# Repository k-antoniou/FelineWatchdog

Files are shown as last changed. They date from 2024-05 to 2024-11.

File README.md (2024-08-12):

# 🐱 Feline Watchdog: Missing Cat Alert System
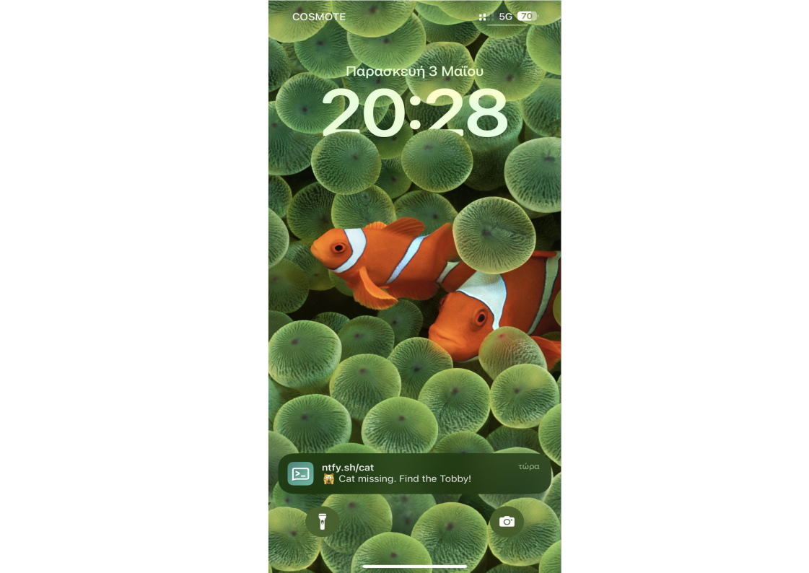
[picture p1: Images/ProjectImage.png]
ProjectImage


Feline Watchdog is an ESP32-based system designed to monitor the Wi-Fi connection between your cat's collar-mounted ESP32 device and your home network. If the Wi-Fi connection is lost, indicating that your cat may have wandered out of range, the system sends a notification to your iOS or Android device using the ntfy Linux tool.

## Overview

Have you ever worried about your cat wandering too far from home? Feline Watchdog provides peace of mind by alerting you when your cat goes missing. By monitoring the Wi-Fi connection between your cat's collar-mounted ESP32 device and your home network, Feline Watchdog can detect when your cat is out of range and send you an alert notification on your mobile device.

## 🔧 Prerequisites

- ESP32 microcontroller
- Raspberry Pi (Optional)
- Docker (if using Raspberry Pi)
- Router (if not using Raspberry Pi)

## Embedded System Configuration

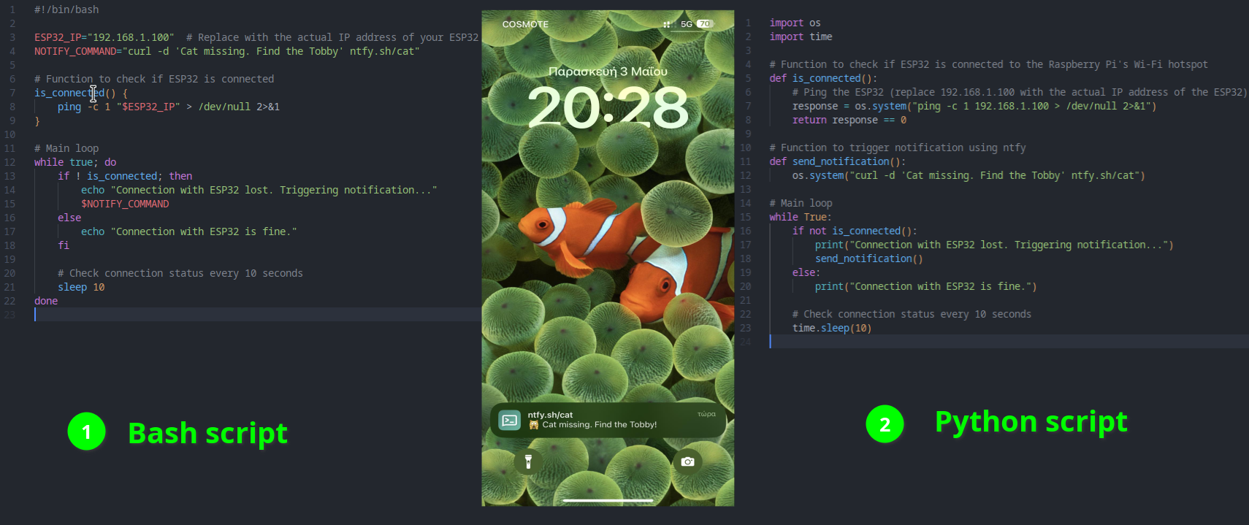
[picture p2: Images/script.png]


<p align="center">
  <b>Two implementations of Embedded System Configuration</b>
</p>

### Option 1: With Raspberry Pi

1. **Setting Up a Wi-Fi Hotspot on Embedded System**

   - For detailed instructions on setting up a Wi-Fi hotspot on your embedded system, please refer to the [Wi-Fi Hotspot Setup Instructions](WiFi_hotspot.md).

   - Use the provided bash script using the **nmcli** tool to create a Wi-Fi hotspot on the Raspberry Pi. 
    ```bash
    bash create_hotspot.sh
    ```
    or
    ```bash
    ./create_hotspot.sh
    ```
  2. **Install Docker on your Raspberry Pi**
  ```bash
  sudo docker --version
  Docker version 20.10.21, build 20.10.21-0ubuntu1~18.04.3
  ```
  ```bash
  docker run \
    -v /var/cache/ntfy:/var/cache/ntfy \
    -v /etc/ntfy:/etc/ntfy \
    -p 80:80 \
    -itd \
    binwiederhier/ntfy \
      serve \
      --cache-file /var/cache/ntfy/cache.db
  ```
## 📡 ESP32 Configuration and Notification Setup

### Option 1: Using Raspberry Pi as a Wi-Fi Hotspot

1. **ESP32 Configuration**
   - Upload the `cat.ino` code to your ESP32.
   - The ESP32 will connect to the Wi-Fi hotspot created by the Raspberry Pi.
   - Once connected, the assigned IP address will be printed to the serial monitor.

2. **Raspberry Pi Monitoring and Notification**
   - The Raspberry Pi continuously monitors the connection status of the ESP32.
   - If the connection is lost, it triggers a notification using ntfy.

### Option 2: Direct Connection to Router

For a basic example of using NTFY with ESP boards, check out the [ntfy_on_a_chip repository](https://github.com/gergepalfi/ntfy_on_a_chip). It provides a foundational setup for communicating with the NTFY server and can be adapted for various projects, including this.

1. **Connect ESP32 Directly to Router**
   - Configure your ESP32 to connect directly to your home Wi-Fi network (router).

2. **ESP32 Configuration**
   - Upload the `cat.ino` code to your ESP32.
   - The ESP32 will connect to the specified Wi-Fi network and print the assigned IP address to the serial monitor.

3. **Notification Setup**
   - Set up ntfy or another notification service on a server or computer within your home network.
   - This service will monitor the connection status of the ESP32.
   - If the connection is lost, it triggers a notification using ntfy or a similar service.

### Notes
- Ensure that your network's firewall settings allow communication between the ESP32 and the notification service.
- Configure ntfy or your chosen notification service according to the service's documentation for optimal performance.

## 🔩 PCB Design

  ### Dual Power Sources: Li-ion Battery and USB

  This setup allows the ESP32 to be powered either by a Li-ion battery or directly from a USB source via a voltage regulator.

  ### Li-ion Battery Connection
  - The Li-ion battery is connected to the **BATT+** and **BATT-** terminals of the charger module.
  - **BATT+** from the charger module is connected to the 3.3V input of the ESP32 through a Schottky diode.
  - **BATT-** is connected to the GND of the ESP32.

  ### USB Power Connection (For Re-programming)
  - The 5V line from the USB is connected to the **VIN** of the voltage regulator.
  - **GND** from the USB is connected to the GND of the voltage regulator.
  - The 3.3V output of the voltage regulator is connected to the 3.3V input of the ESP32 through a Schottky diode.

  Screenshots from KiCad:

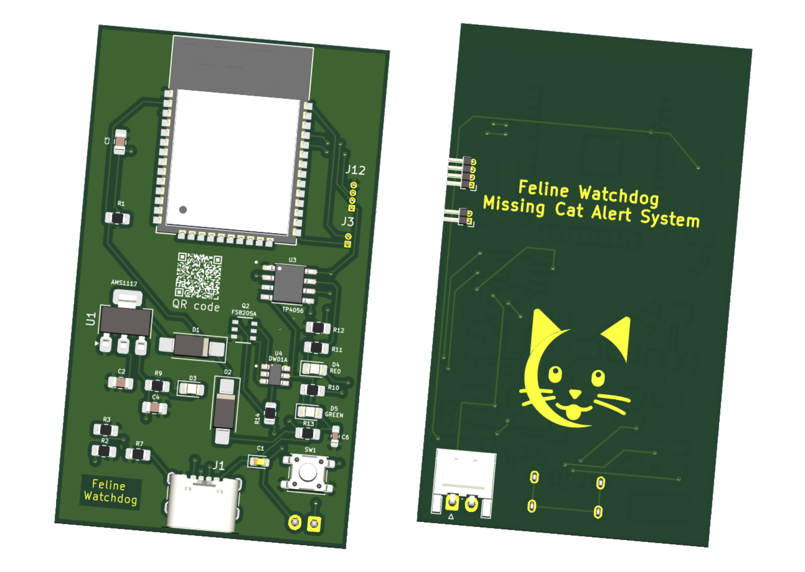
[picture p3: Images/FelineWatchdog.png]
  

  Screenshots from Fusion 360:

  ### Important Notes
  - Schottky diodes are used to prevent backfeeding between the battery and USB power sources.

  ## 🏗️ 3D Design

  Screenshots from Fusion 360:
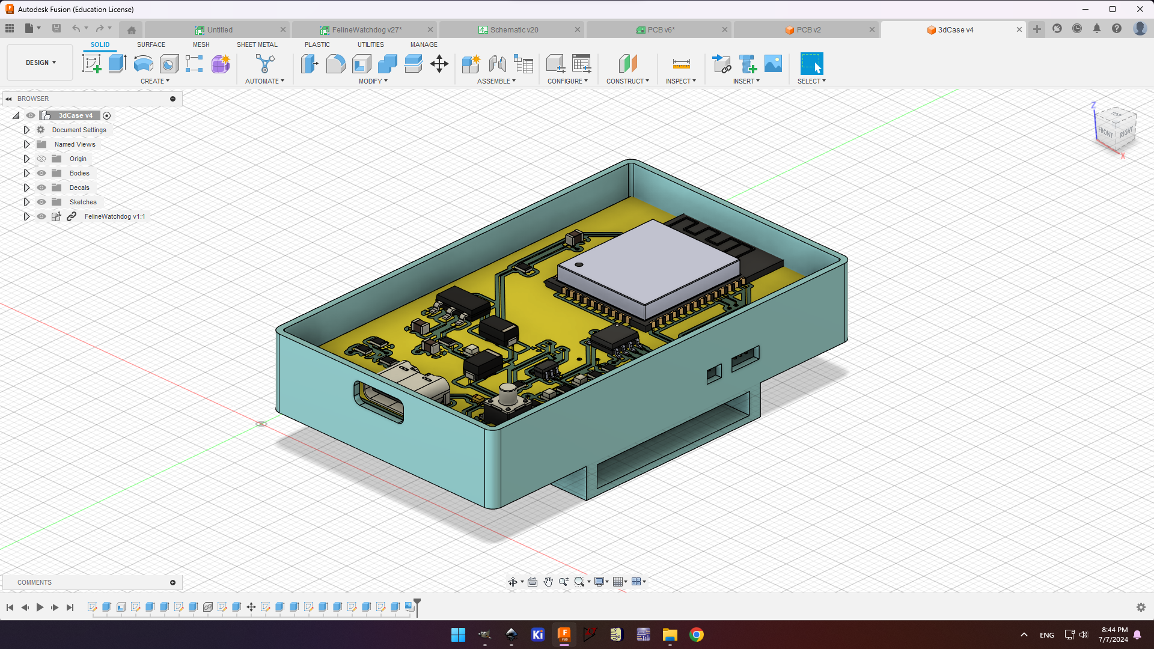
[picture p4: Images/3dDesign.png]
  

  ## 3D Printed Case

  Screenshots of the printed 3D case:
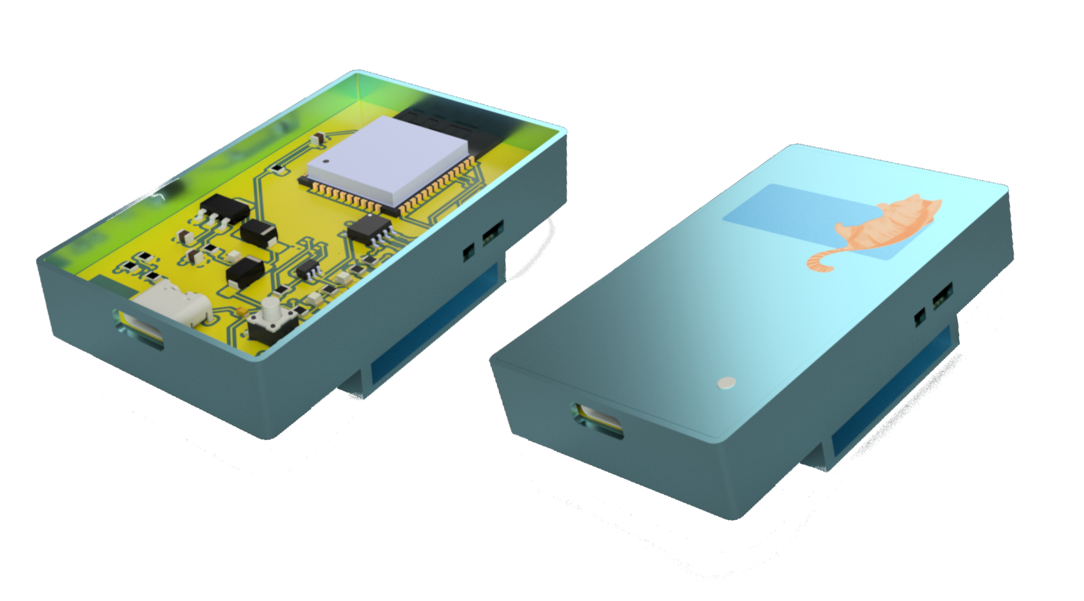
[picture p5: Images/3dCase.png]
  

  ## To Do

  - [x] Implement notification functionality using ntfy for sending alerts to iOS or Android devices.
  - [x] Implementation without a middle point such as Raspberry Pi, but directly with a router and ESP32.
  - [ ] Lower power consumption.
  - [ ] Implement HTTP communication method for sending alerts to a designated endpoint.
  - [ ] Implement MQTT communication method for publishing messages to a specific topic on an MQTT broker.
  - [ ] Ensure seamless integration of these functionalities within a Docker container on the Raspberry Pi.
  - [ ] Document setup and configuration steps for each notification method.
  - [ ] Test and validate the system's functionality across different scenarios.
  - [ ] Gather feedback and suggestions from users for further enhancements.

  ## 🧑‍💻 Authors

  - 

  - 

  ## 👥 Contributors

  Contributions are welcome! Feel free to submit pull requests or open issues if you encounter any problems.

   ## 🙏 Acknowledgements

   - A special thanks to the [ntfy_on_a_chip](https://github.com/gergepalfi/ntfy_on_a_chip) repository by [Gerge](https://github.com/gergepalfi). The example code and documentation provided were instrumental in implementing the direct connection option for the Feline Watchdog project. The guidance on using NTFY with ESP boards and the detailed explanation of HTTPS communication enabled us to streamline our setup by connecting the ESP32 directly to a router without needing an intermediate server like a Raspberry Pi. Your work greatly facilitated our development process and contributed to the success of the Feline Watchdog system. Thank you!

   - We would also like to acknowledge the creators of the [ntfy](https://ntfy.sh) app. The app’s simplicity and functionality made it easy to send and receive notifications, which is a core feature of the Feline Watchdog system. The ability to integrate it seamlessly into our project greatly enhanced its effectiveness.

   ## 📜 License
   
   This project is licensed under the [GPLv3 License](https://opensource.org/licenses/GPL-3.0) - see the [LICENSE](LICENSE) file for details.

   - 

**Thank you for visiting FelineWatchdog!** ✨

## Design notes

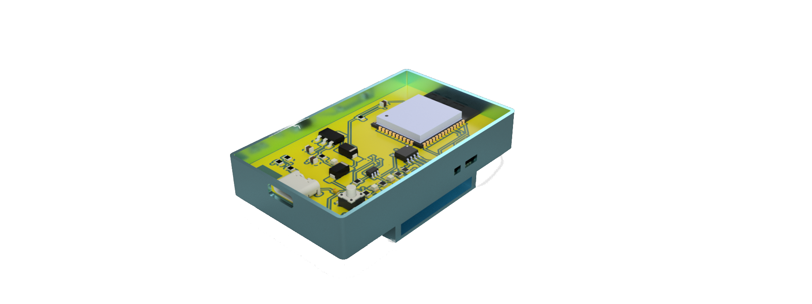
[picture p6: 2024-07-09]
Images/3dCaseOpened.png

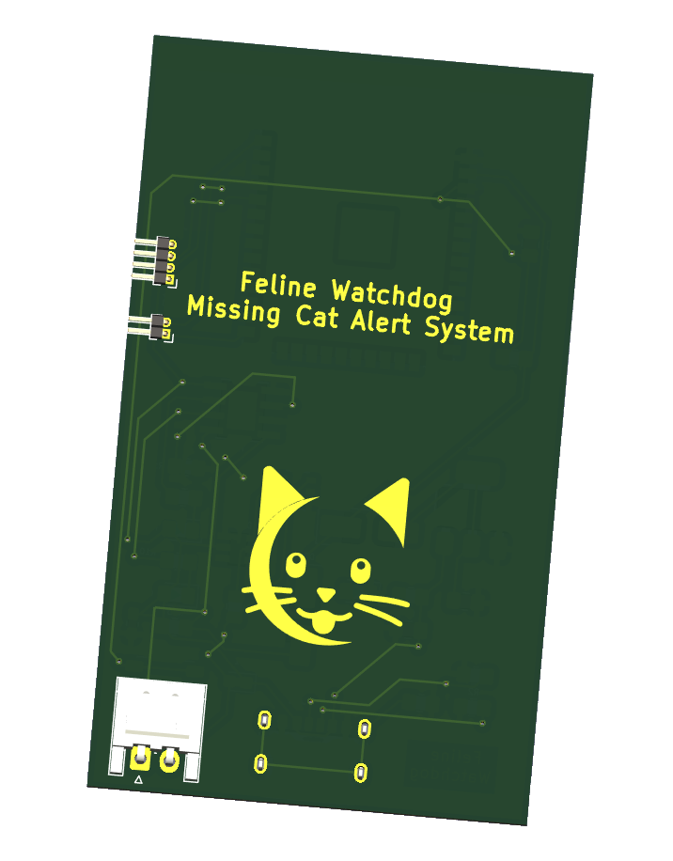
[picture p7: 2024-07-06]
Images/FelineWatchdog2.png

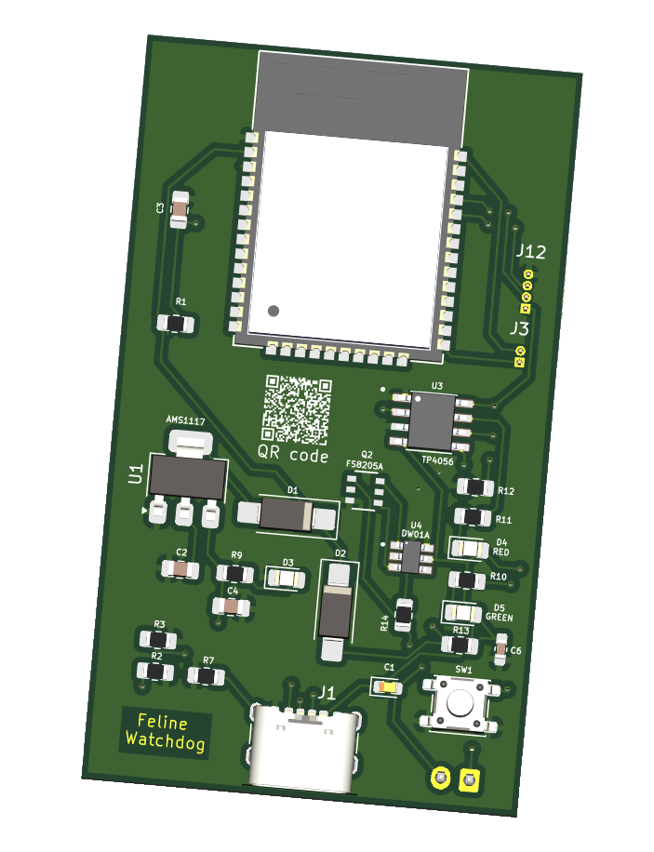
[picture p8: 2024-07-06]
Images/FelineWatchdog1.png

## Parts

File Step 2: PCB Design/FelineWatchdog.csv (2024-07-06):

Reference | Value | Datasheet | Footprint | Qty | DNP
C1 | 0.1uf | ~ | Capacitor_Tantalum_SMD:CP_EIA-1608-08_AVX-J | 1
C2,C3,C4 | 10uF | ~ | Capacitor_SMD:C_0805_2012Metric_Pad1.18x1.45mm_HandSolder | 3
C6 | 0.1uF | ~ | Capacitor_SMD:C_0603_1608Metric_Pad1.08x0.95mm_HandSolder | 1
D1,D2 | SS14 | https://www.vishay.com/docs/88746/ss12.pdf | Diode_SMD:D_SMA_Handsoldering | 2
D3 | LED | ~ | LED_SMD:LED_0805_2012Metric_Pad1.15x1.40mm_HandSolder | 1
D4 | RED | ~ | LED_SMD:LED_0805_2012Metric_Pad1.15x1.40mm_HandSolder | 1
D5 | GREEN | ~ | LED_SMD:LED_0805_2012Metric_Pad1.15x1.40mm_HandSolder | 1
J1 | USB_C_Receptacle_PowerOnly_6P | https://www.usb.org/sites/default/files/documents/usb_type-c.zip | Connector_USB:USB_C_Receptacle_GCT_USB4125-xx-x-0190_6P_TopMnt_Horizontal | 1
J2 | Conn_01x02_Socket | ~ | Connector_JST:JST_EH_S2B-EH_1x02_P2.50mm_Horizontal | 1
J3 | Conn_01x02_Pin | ~ | Connector_PinHeader_1.00mm:PinHeader_1x02_P1.00mm_Horizontal | 1
J9 | USB_B_Micro | ~ | Connector_USB:USB_Micro-B_Amphenol_10118194_Horizontal | 1
J12 | Conn_01x04_Socket | ~ | Connector_PinHeader_1.00mm:PinHeader_1x04_P1.00mm_Horizontal | 1
Q2 | FS8205A | FS8205A | ul_FS8205A:SOT-23-6L_TCP-L | 1
R1,R12 | 10k | ~ | Resistor_SMD:R_0805_2012Metric_Pad1.20x1.40mm_HandSolder | 2
R2,R3 | 5k1 | ~ | Resistor_SMD:R_0805_2012Metric_Pad1.20x1.40mm_HandSolder | 2
R7,R8,R9 | 1M | ~ | Resistor_SMD:R_0805_2012Metric_Pad1.20x1.40mm_HandSolder | 3
R10,R11,R14 | 1k | ~ | -- mixed values -- | 3
R13 | 100 | ~ | Resistor_SMD:R_0805_2012Metric_Pad1.20x1.40mm_HandSolder | 1
SW1 | RESET | http://www.apem.com/int/index.php?controller=attachment&id_attachment=1371 | VeisLibrary:MySwitch_SW_SPST_PTS647_Sx50 | 1
U1 | AMS1117-3.3 | http://www.advanced-monolithic.com/pdf/ds1117.pdf | Package_TO_SOT_SMD:SOT-223-3_TabPin2 | 1
U3 | TP4056 |  | TP4056:SOP127P600X175-9N | 1
U4 | DW01A |  | DW01A:SOT95P280X145-6N | 1
U5 | ESP-32S | ESP-32S | ul_ESP-32S:ESP-32S_AIT | 1

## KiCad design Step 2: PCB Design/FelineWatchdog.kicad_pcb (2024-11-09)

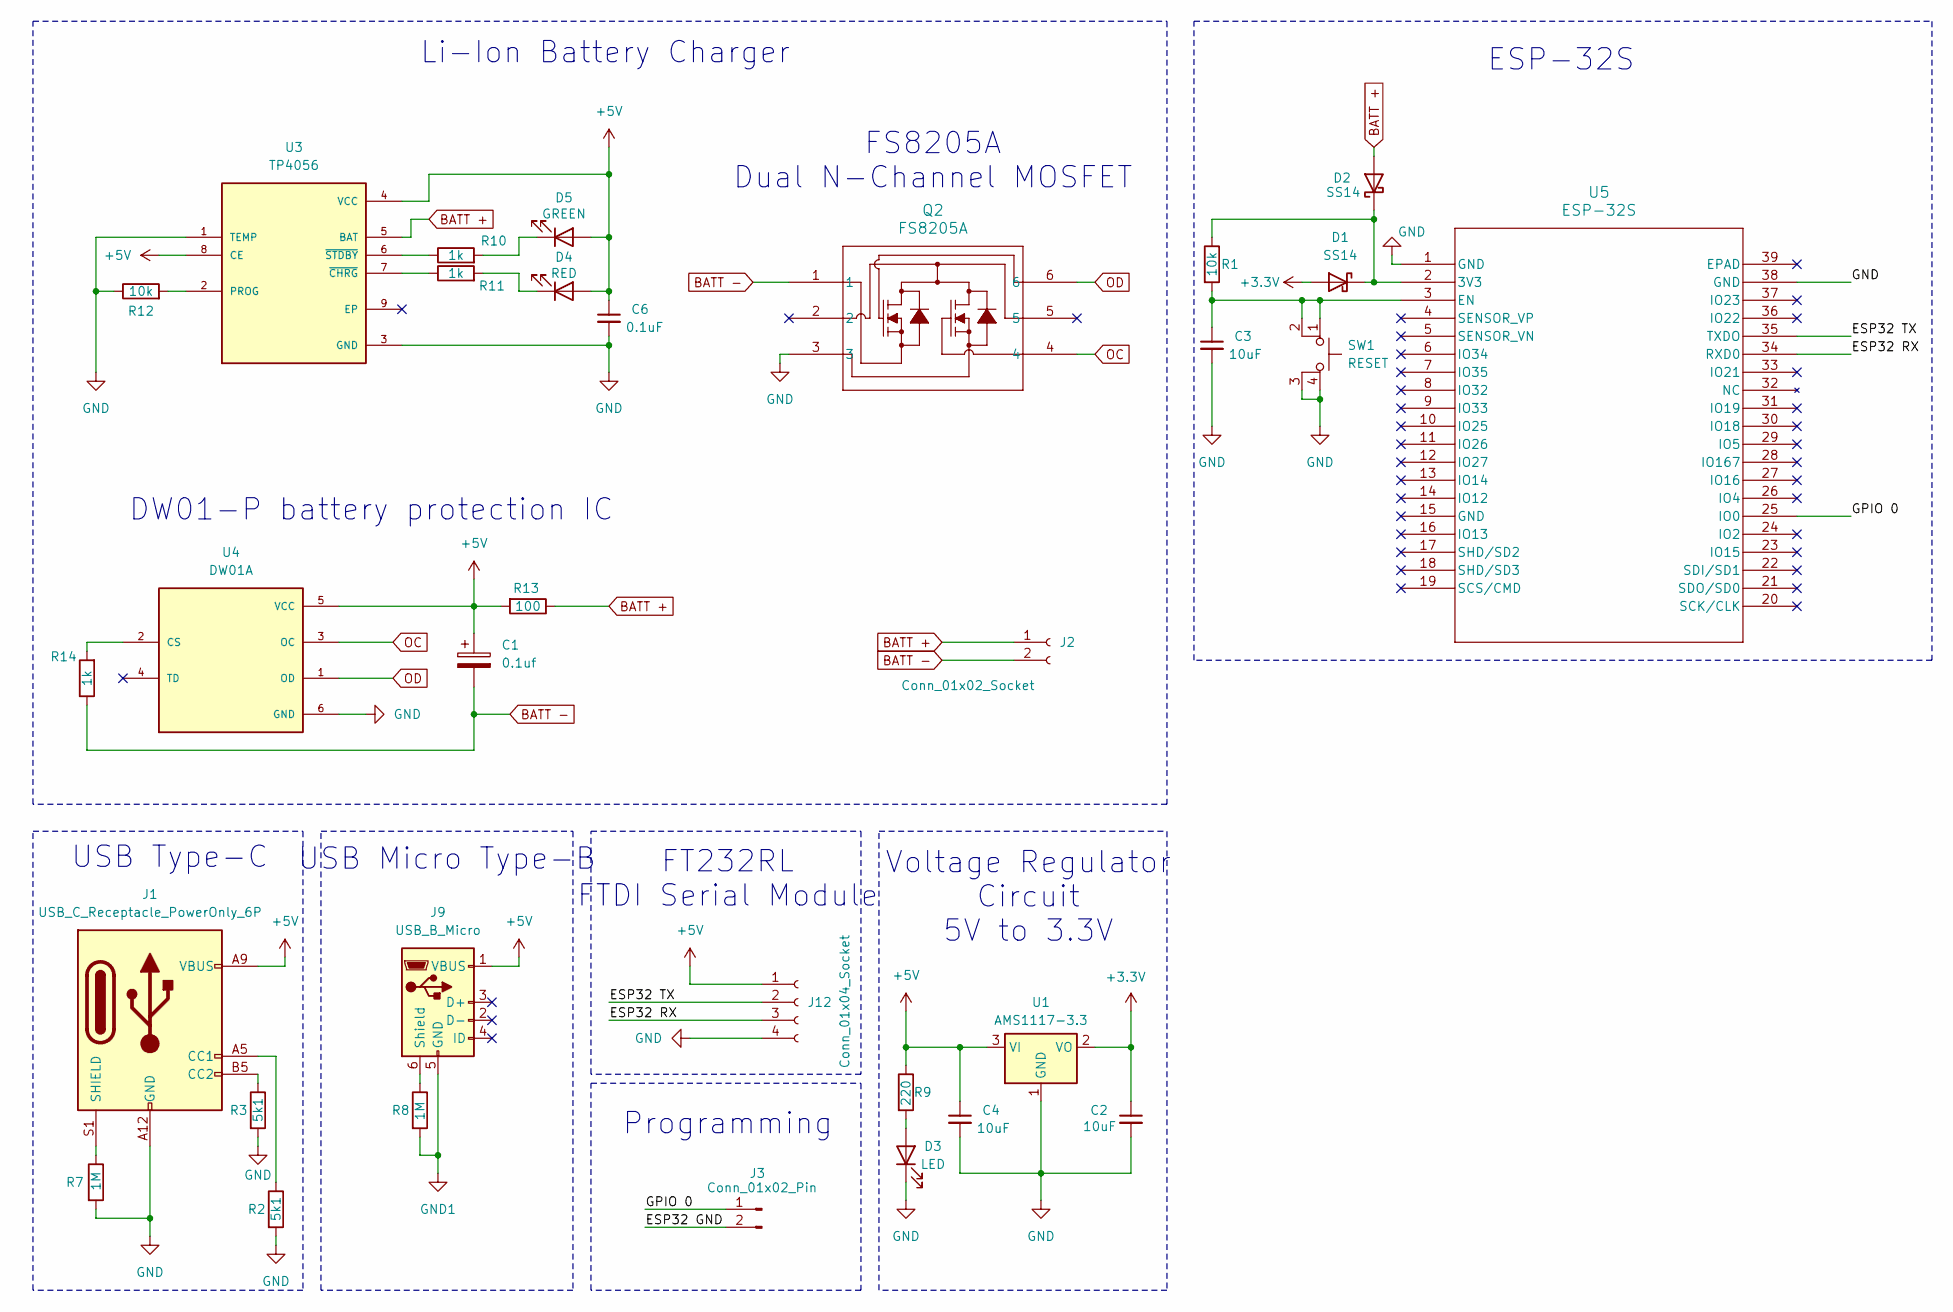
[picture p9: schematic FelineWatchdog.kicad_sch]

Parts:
C1: 0.1uf; CP_EIA-1608-08_AVX-J
C2, C3, C4: 10uF; C_0805_2012Metric_Pad1.18x1.45mm_HandSolder
C6: 0.1uF; C_0603_1608Metric_Pad1.08x0.95mm_HandSolder
D1, D2: SS14; D_SMA_Handsoldering
D3: LED; LED_0805_2012Metric_Pad1.15x1.40mm_HandSolder
D4: RED; LED_0805_2012Metric_Pad1.15x1.40mm_HandSolder
D5: GREEN; LED_0805_2012Metric_Pad1.15x1.40mm_HandSolder
J1: USB_C_Receptacle_PowerOnly_6P; USB_C_Receptacle_GCT_USB4125-xx-x-0190_6P_TopMnt_Horizontal
J2: Conn_01x02_Socket; JST_EH_S2B-EH_1x02_P2.50mm_Horizontal
J3: Conn_01x02_Pin; PinHeader_1x02_P1.00mm_Horizontal
J9: USB_B_Micro; USB_Micro-B_Amphenol_10118194_Horizontal
J12: Conn_01x04_Socket; PinHeader_1x04_P1.00mm_Horizontal
Q2: FS8205A; SOT-23-6L_TCP-L
R1, R12: 10k; R_0805_2012Metric_Pad1.20x1.40mm_HandSolder
R2, R3: 5k1; R_0805_2012Metric_Pad1.20x1.40mm_HandSolder
R7, R8: 1M; R_0805_2012Metric_Pad1.20x1.40mm_HandSolder
R9: 220; R_0805_2012Metric_Pad1.20x1.40mm_HandSolder
R10, R11: 1k; R_0805_2012Metric_Pad1.20x1.40mm_HandSolder
R13: 100; R_0805_2012Metric_Pad1.20x1.40mm_HandSolder
R14: 1k; R_0805_2012Metric
SW1: RESET; MySwitch_SW_SPST_PTS647_Sx50
U1: AMS1117-3.3; SOT-223-3_TabPin2
U3: TP4056; SOP127P600X175-9N
U4: DW01A; SOT95P280X145-6N; PARTREV 1.8
U5: ESP-32S; ESP-32S_AIT

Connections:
+3.3V: C2.1, D1.2 (A), U1.2 (VO)
+5V: C1.1, C4.1, C6.1, D4.2 (A), D5.2 (A), J1.A9 (VBUS), J1.B9 (VBUS), J9.1 (VBUS), J12.1, R9.1, R13.2, U1.3 (VI), U3.4 (VCC), U3.8 (CE), U4.5 (VCC)
/ESP32 RX: J12.3, U5.34 (RXD0)
/ESP32 TX: J12.2, U5.35 (TXDO)
/GPIO 0: J3.1, U5.25 (IO0)
BATT +: D2.2 (A), J2.1, R13.1, U3.5 (BAT)
BATT -: C1.2, J2.2, Q2.1, R14.1
unnamed: D1.1 (K), D2.1 (K), R1.1, U5.2 (3V3)
unnamed: D3.2 (A), R9.2
unnamed: D4.1 (K), R11.2
unnamed: D5.1 (K), R10.2
unnamed: J1.A5 (CC1), R2.1
unnamed: J1.B5 (CC2), R3.1
unnamed: J1.S1 (SHIELD), R7.1
unnamed: J9.5 (GND), R8.2
unnamed: J9.6 (Shield), R8.1
unnamed: R12.2, U3.2 (PROG)
unnamed: R11.1, U3.7 (~CHRG)
unnamed: R10.1, U3.6 (~STDBY)
unnamed: R14.2, U4.2 (CS)
unnamed: C3.1, R1.2, SW1.1, SW1.2, U5.3 (EN)
OC: Q2.4, U4.3 (OC)
OD: Q2.6, U4.1 (OD)

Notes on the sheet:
ESP-32S
DW01-P battery protection IC
FS8205A Dual N-Channel MOSFET
FT232RL FTDI Serial Module
Voltage Regulator Circuit 5V to 3.3V
Li-Ion Battery Charger
USB Type-C
USB Micro Type-B
Programming

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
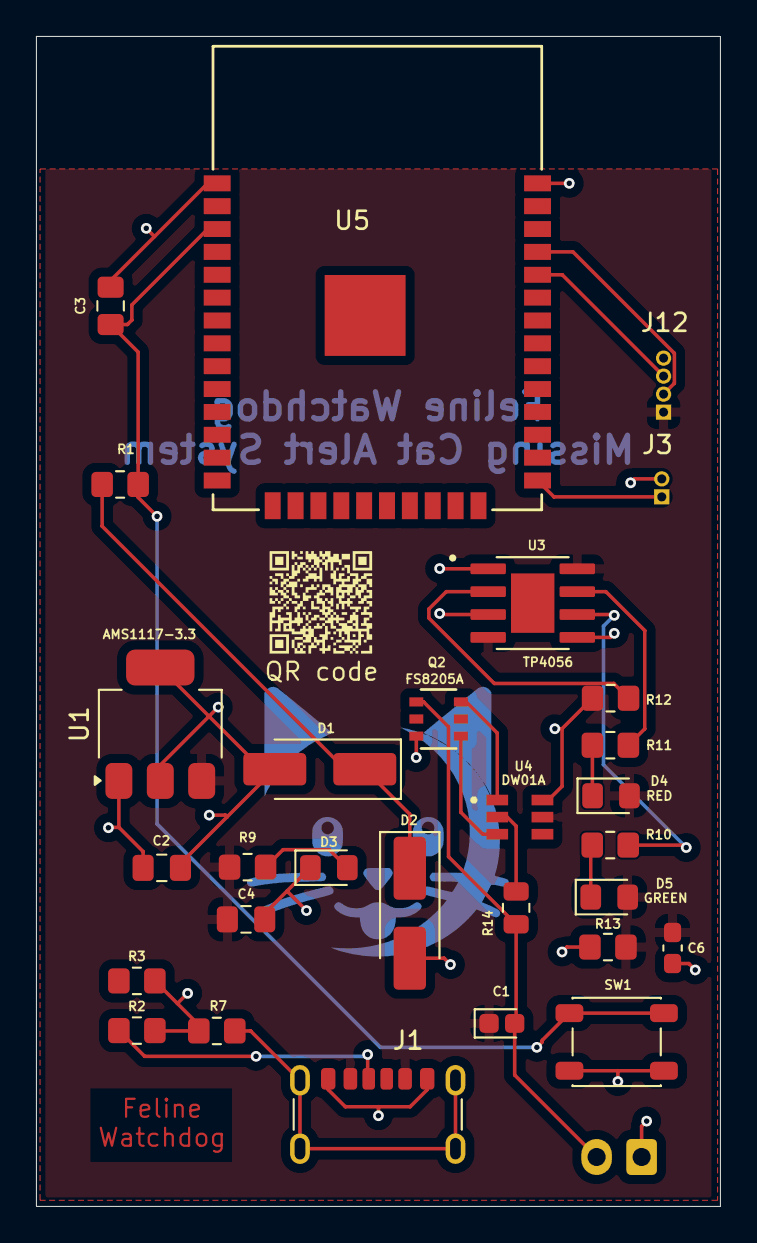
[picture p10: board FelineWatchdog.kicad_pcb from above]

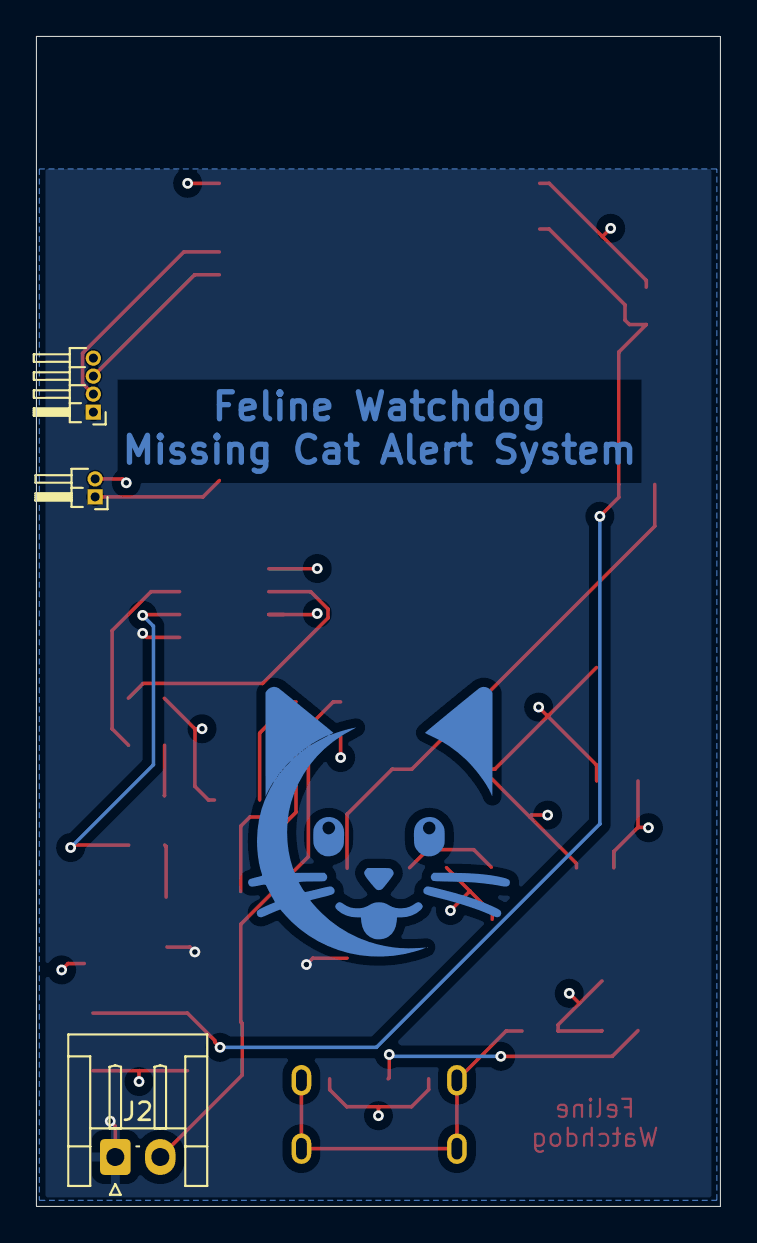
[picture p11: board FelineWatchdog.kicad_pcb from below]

Board: 4 copper layers, 38.0 x 65.0 mm, 32 parts (4 on the bottom side), 22 nets.

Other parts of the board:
G1: LOGO; cat
G2: LOGO; QRcat

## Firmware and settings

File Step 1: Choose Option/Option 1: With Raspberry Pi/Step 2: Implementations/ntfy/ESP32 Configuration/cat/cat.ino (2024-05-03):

#include <WiFi.h>

const char* ssid = "FelineWatchdog-Hotspot";
const char* password = "12345678";

void setup() {
  Serial.begin(115200);

  // Connect to Wi-Fi hotspot
  WiFi.begin(ssid, password);

  Serial.println("Connecting to Wi-Fi hotspot...");

  while (WiFi.status() != WL_CONNECTED) {
    delay(500);
    Serial.print(".");
  }

  Serial.println("");
  Serial.println("Connected to Wi-Fi hotspot");
  Serial.print("IP Address: ");
  Serial.println(WiFi.localIP());
}

void loop() {
  // Your main code here
}

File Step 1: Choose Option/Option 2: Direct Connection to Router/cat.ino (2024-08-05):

```cpp
#include <WiFi.h>
#include <HTTPClient.h>
#include <ArduinoJson.h>

#define ssid "YOUR_SSID"            // Replace with your WiFi SSID
#define password "YOUR_PASSWORD"    // Replace with your WiFi password
String serverName = "https://ntfy.sh/cat";  // URL to send notifications to
// #define base64_login ""         // Uncomment and set if you have access control. Use 'echo -n "user:pass" | base64' to generate this.
#define getinterval 10000          // Interval for checking WiFi signal strength (in milliseconds)

// Root certificate for HTTPS
const char root_ca[] PROGMEM = R"rawliteral(
-----BEGIN CERTIFICATE-----
MIIE3TCCA8WgAwIBAgISBFCU2/1Fxw45z6TIm6oH6rTzMA0GCSqGSIb3DQEBCwUA
MDMxCzAJBgNVBAYTAlVTMRYwFAYDVQQKEw1MZXQncyBFbmNyeXB0MQwwCgYDVQQD
EwNSMTEwHhcNMjQwNzE3MTYxMzM5WhcNMjQxMDE1MTYxMzM4WjASMRAwDgYDVQQD
EwdudGZ5LnNoMIIBIjANBgkqhkiG9w0BAQEFAAOCAQ8AMIIBCgKCAQEAvN5knHxZ
YnZxU6pscrlAi/srb4Lko19Gp0YXCqH1cteci8Kxx5V2aH0NM1g+hmUViuUVtC16
HxzxLxic+bzlNZzLanvjoTbyxsp8RdrfLsluyKpem4XO8KTKzLew0ohajdX80Opc
4Fxo1HdpYYs2Pj4sTsw9PEUVFH+DQD+V+cG6GiJfcQIJ1Wohb6y0yXxxmMz2ysiu
g+GiJ1smW/5Ys+oO4bDQYnS/em/2JmwUh+RwkIIqBiAEMlsqVLmdUP0sCcepy2EG
boSfCF0qfzMjSCPTBJ0Upe8yIvXNKgdtMX8pup1BFRRRuWSuYh2OBZLT6lVZD0qh
9Rx1OEz452birwIDAQABo4ICCjCCAgYwDgYDVR0PAQH/BAQDAgWgMB0GA1UdJQQW
MBQGCCsGAQUFBwMBBggrBgEFBQcDAjAMBgNVHRMBAf8EAjAAMB0GA1UdDgQWBBQQ
W2B/qDtGJ1t9sk1NaFTL+o6SNTAfBgNVHSMEGDAWgBTFz0ak6vTDwHpslcQtsF6S
LybjuTBXBggrBgEFBQcBAQRLMEkwIgYIKwYBBQUHMAGGFmh0dHA6Ly9yMTEuby5s
ZW5jci5vcmcwIwYIKwYBBQUHMAKGF2h0dHA6Ly9yMTEuaS5sZW5jci5vcmcvMBIG
A1UdEQQLMAmCB250Znkuc2gwEwYDVR0gBAwwCjAIBgZngQwBAgEwggEDBgorBgEE
AdZ5AgQCBIH0BIHxAO8AdQB2/4g/Crb7lVHCYcz1h7o0tKTNuyncaEIKn+ZnTFo6
dAAAAZDBr3ZXAAAEAwBGMEQCIA9d2Bjk988OHJhM9maYn+ujsvdRqfgWmX3k4Slj
RHz/AiBFOdbYavwOfNpBBgFpzHHw4L3hkxB/TJWcf1Ns+t/PLQB2ABmYEHEJ8NZS
LjCA0p4/ZLuDbijM+Q9Sju7fzko/FrTKAAABkMGvdkgAAAQDAEcwRQIhAPGGXZ1Y
dL7bg8kwqHijlIgcBLyiRUo7P/d75BG16OIuAiBPociCWuS5E6dJrMGVo6FNwER8
Y/fpb/el9t3QWNcqczANBgkqhkiG9w0BAQsFAAOCAQEApygM7Z6B+275+0hhZxQW
/2u9qV2gw1fXChy1ecQ7wqhx/Dasw4N5aC/NwXUQ0+tIhnxSO2CfDOdQTqFNX3ua
6HszgX87WPFNLCHcWzOMWwq+HYNf2QK/QlB396flw6njSqdN0lnDJZC1Ncf494vD
IpQKwZHWhgmBVI2EJQDyXOZ2D0wrTfly0ToCLGmRTVWMEI7KD3/EqCNs3uoUze2s
saL/fxoLv+nm7cpQOtz1pgnwUXNFRXrdr7Lpi57TXXzt4vRdrFDZ/ylReboW7ZDG
7xFSTnG+eZ7JsOSqF1DwedbApG8wA8y8CMiSNNtlW5x5hOa34TmJJ4TVZd1Y5TIF
pw==
-----END CERTIFICATE-----
)rawliteral";

// Global variables
unsigned long gettimestamp = 0;           // Millis timestamp of last HTTPS GET call
unsigned long lastMessageTime = 1666810118; // UNIX time of last message that was processed (prevents processing of the same message multiple times)

// Setup function runs once when the board is powered on or reset
void setup() {
  Serial.begin(115200); // Start serial communication
  WiFi.begin(ssid, password); // Connect to WiFi
  Serial.print("Connecting to WiFi..");
  while (WiFi.status() != WL_CONNECTED) {
    delay(1000);
    Serial.print(".");
  }
  Serial.println("..Connected");
}

// Main loop
void loop() {
  if ((gettimestamp + getinterval) < millis()) {
    checkWiFiSignalStrength(); // Check WiFi signal strength every interval
    gettimestamp = millis();
  }
}

// Function to check WiFi signal strength
void checkWiFiSignalStrength() {
  int32_t rssi = WiFi.RSSI(); // Get RSSI (Received Signal Strength Indicator)
  int32_t signalStrength = map(rssi, -100, -50, 0, 100); // Map RSSI to percentage (0 to 100)

  Serial.print("WiFi Signal Strength: ");
  Serial.print(signalStrength);
  Serial.println("%");

  // Send notification if signal strength is less than 15%
  if (signalStrength < 15) {
    Serial.println("Signal strength is less than 15%. Sending notification...");
    sendMissingCatNotification(); // Send notification if signal is weak
  }
}

// Function to send a notification when the cat is missing
void sendMissingCatNotification() {
  if (WiFi.status() == WL_CONNECTED) { // Check if WiFi is connected
    HTTPClient https;
    if (https.begin(serverName, root_ca)) { // Start HTTPS connection
      https.addHeader("Content-Type", "text/plain"); // Set content type
      // #ifdef base64_login // Uncomment if using basic authentication
      // https.addHeader("Authorization", "Basic "base64_login);
      // #endif
      https.addHeader("title", "Cat Status"); // Set notification title
      String httpsRequestData = "The cat is missing"; // Notification message
      int httpsResponseCode = https.POST(httpsRequestData); // Send POST request
      Serial.print("[HTTPS] POST... code: ");
      Serial.println(httpsResponseCode); // Print response code
      https.end(); // End HTTPS connection
    } else {
      Serial.println("[HTTPS] Unable to connect"); // Connection failed
    }
  }
}

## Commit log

2024-08-05 Remove outdated files and directories; add new design files
    [FelineWatchdog.csv, FelineWatchdog.kicad_pcb, FelineWatchdog.kicad_sch]
2024-08-05 Add implementation for direct connection to router with ESP32
2024-11-09 Switch to 4-layer PCB stackup with dedicated power and ground planes
    - **Top Layer**: Filled zone for **BAT+** (Battery Positive).
    - **Inner Layer 1**: 3.3V power plane for ESP32 and low-voltage components.
    - **Inner Layer 2**: Shared **GND** plane with **BAT-** (Battery Negative).
    - **Bottom Layer**: Additional **BAT+** power distribution.
    Inner layers ensure stable power delivery, improved signal integrity, and reduced EMI.
    [FelineWatchdog.kicad_pcb, FelineWatchdog.kicad_sch]
2025-01-17 Added .gitignore for KiCad PCB project to exclude temporary and exported files

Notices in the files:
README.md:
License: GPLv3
